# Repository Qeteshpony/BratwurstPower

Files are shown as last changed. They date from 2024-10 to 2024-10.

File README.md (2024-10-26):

# BratwurstPower



3D Render Top
3D Render Bottom

[Hardware Documentation](https://qeteshpony.github.io/BratwurstPower)

### What's this?

A power supply for a complete, Raspberry Pi based ADS-B Receiver Setup with independent power rails for the different components.

We sometimes face the problem that a normal Raspberry Pi power supply does not deliver enough power for the Raspi itself, the SDR Stick and possible other components like a display or even an SSD. 

This board can be mounted underneath a Raspberry Pi and deliver stable 5.x V with up to 3 A to it. 

In addition to that it can supply two USB devices and another external device with also 5.x V and 3 A each, provided the input has enough power and the maximum input current does not surpass 5A. 

Each outputs voltage can be calibrated from ~5.06 to ~5.6 V with a trimpot and the two USB outputs are passing USB2 signals from two USB-C connectors that can be hooked up to the Raspberry Pi. If you need USB3, you can use an external Y-cable. 

## What else is on the board?

The onboard circuitry is powered by its own 3.3V LDO regulator which is fed by the power rail for the Raspberry Pi since that one is always running. The LDO can provide a maximum of 200mA to also power small external loads on the GPIO connector. 

There is an INA219 power monitor connected to the main input and each output with a 10mΩ shunt resistor to measure current and voltage. 

The onboard I2C bus is connected to all of the INA219 and a PCA9557

| Device  | I2C-Address |
|:---|:---|
| INA219 Raspi | 0x40 |
| INA219 USB1  | 0x41 |
| INA219 USB2  | 0x42 |
| INA219 EXT | 0x43 |
| INA219 Main  | 0x44 |
| PCA9557 | 0x1F |

The PCA9557 I/O expander allows to switch off power to the USB-ports and the external power. It also has an LED connected that can be used for showing a warning state or similar. The other 4 pins are broken out on a header.

| PCA9557 Pin | Function |
|:---|:---|
| IO0 | LED  |
| IO1 | GPIO 1 (Opt: Raspi EN) |
| IO2 | GPIO 2 |
| IO3 | GPIO 3 |
| IO4 | GPIO 4 |
| IO5 | USB2 EN |
| IO6 | USB1 EN |
| IO7 | EXT EN |

Each voltage channel has a solder jumper to force-enable it. The USB power rails are also enabled as soon as their input usb port gets connected to the Raspberry Pi. In addition to that, all three external power connections can be controlled by the PCA9557 and there is an optional connection through a solder jumper to even give control over the Raspberry Pi power supply in case the I2C components on this board are controlled externally e.g. by an ESP. 

### External connections and jumpers
| Designator | Function |
|:---|:---|
| IN | Main Power supply - can be powered with 7 to 17V DC with a maximum of 5A. Nominal Power: 12V. |
| Raspi | Power supply for the Raspberry Pi. This is the only port that is by default always on. |
| USB1/2 in | USB input for external connections. Connect these to the Raspberry pi with normal USB cables. |
| USB1/2 out | Powered USB output for external components, each with its own power supply. |
| EXT | Power supply for other external components, also independently powered. Needs to be enabled through its solder jumper or by the PCA9557. |
| 2x I2C | I2C connection to either the Raspberry Pi or an external controller. The 3.3V connection is just a path-through between the connectors. |
| OTG | Optional connector to access the Raspberry Pis USB-OTG functionality. |
| GPIO | Optional header to use the free pins of the PCA9557. Keep in mind that the onboard 3.3V LDO can not provide more than 200mA. |
| USB1/2 EN | Solder jumper to force-enable the USB power supplies in case you want to use them without a connection to the Raspberry Pi. |
| EXT EN | Solder jumper to enable the EXT power supply. |
| Raspi EN | Solder jumper to connect the EN pin if the Raspi power supply with IO1 of the PCA9557. This can be used to externally hard-reset the Raspberry Pi and should only be used when the board is controlled by an external controller like an ESP. |
| TP1 | Test point to measure the voltage on the Raspberry Pi power supply. |
| TP2 | Test point to measure the voltage on the USB1 power supply. |
| TP3 | Test point to measure the voltage on the USB2 power supply. |
| TP4 | Test point to measure the voltage on the EXT power supply. |
| RV1 | Calibration Potentiometer for the Raspberry Pi power supply. |
| RV2 | Calibration Potentiometer for the USB1 power supply. |
| RV3 | Calibration Potentiometer for the USB2 power supply. |
| RV4 | Calibration Potentiometer for the EXT power supply. |

### Software

Example software to control and monitor this device with Home Assistant can be found [here](https://github.com/Qeteshpony/BratwurstPower.py).

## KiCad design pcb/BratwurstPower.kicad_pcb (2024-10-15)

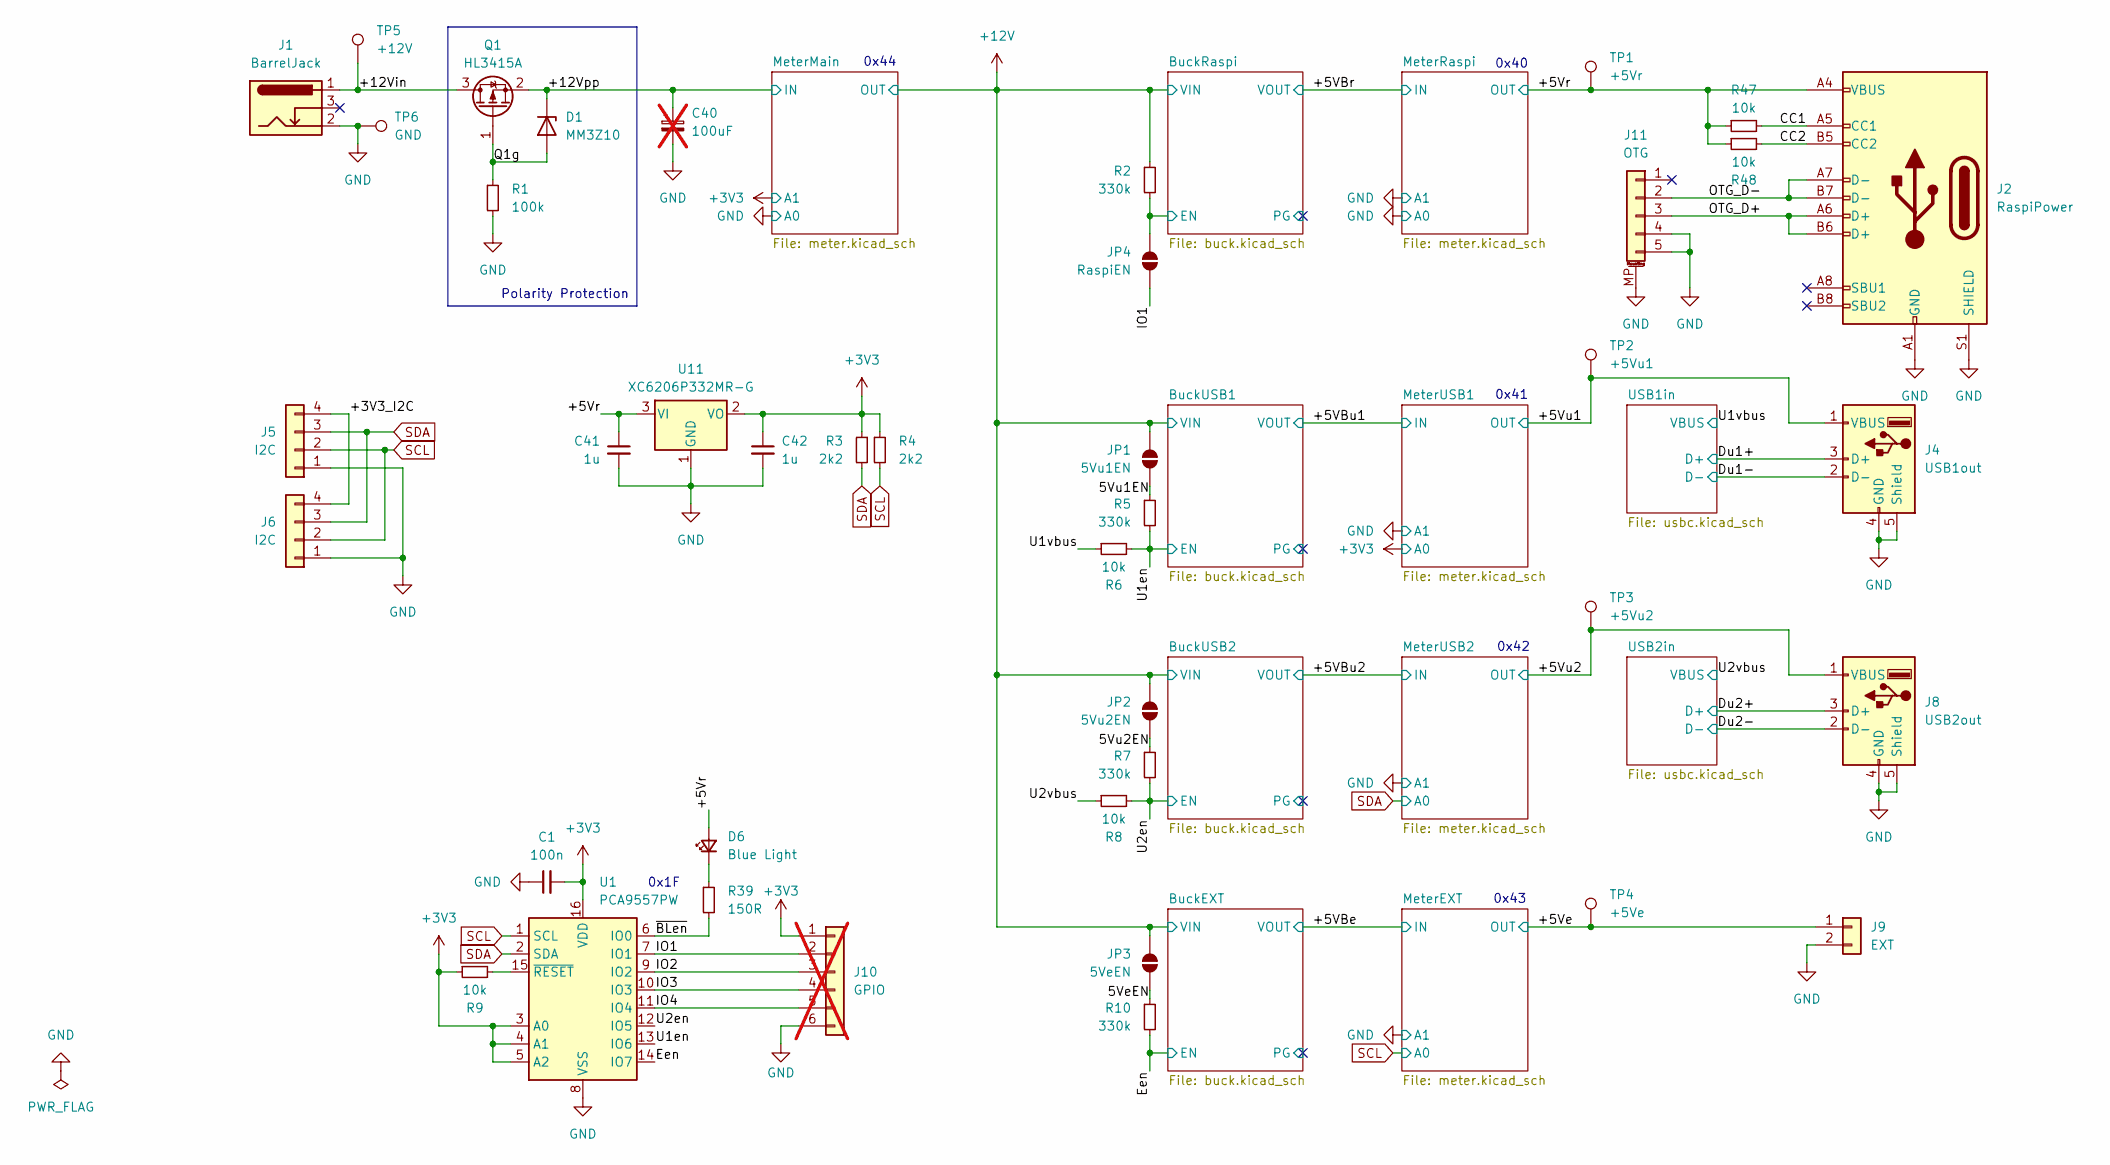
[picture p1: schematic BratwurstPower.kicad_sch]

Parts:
C1: 100n; C_0402_1005Metric; LCSC C307331
C40: 100uF; CP_Radial_D6.3mm_P2.50mm; not fitted
C41, C42: 1u; C_0402_1005Metric; LCSC C52923
D1: MM3Z10; D_SOD-323F; LCSC C19077459
D6: Blue Light; LED_0603_1608Metric_Pad1.05x0.95mm_HandSolder; LCSC C72041
J1: BarrelJack; BarrelJack_Combined
J2: RaspiPower; USB_C_Receptacle_GCT_USB4105-xx-A_16P_TopMnt_Horizontal; LCSC C2988369
J4: USB1out; USB_A_Molex_67643_Horizontal; LCSC C2798029
J5, J6: I2C; JST_PH_S4B-PH-K_1x04_P2.00mm_Horizontal; LCSC C265452
J8: USB2out; USB_A_Molex_67643_Horizontal; LCSC C2798029
J9: EXT; JST_XH_S2B-XH-A_1x02_P2.50mm_Horizontal; LCSC C157931
J10: GPIO; PinHeader_1x06_P2.54mm_Vertical; not fitted
J11: OTG; JST_SH_SM05B-SRSS-TB_1x05-1MP_P1.00mm_Horizontal; LCSC C160404
JP1: 5Vu1EN; SolderJumper-2_P1.3mm_Open_TrianglePad1.0x1.5mm
JP2: 5Vu2EN; SolderJumper-2_P1.3mm_Open_TrianglePad1.0x1.5mm
JP3: 5VeEN; SolderJumper-2_P1.3mm_Open_TrianglePad1.0x1.5mm
JP4: RaspiEN; SolderJumper-2_P1.3mm_Open_TrianglePad1.0x1.5mm
Q1: HL3415A; SOT-23; LCSC C28646270
R1: 100k; R_0402_1005Metric; LCSC C25741
R2, R5, R7, R10: 330k; R_0402_1005Metric; LCSC C25778
R3, R4: 2k2; R_0402_1005Metric; LCSC C25879
R6, R8, R9, R47, R48: 10k; R_0402_1005Metric; LCSC C25744
R39: 150R; R_0402_1005Metric; LCSC C25082
TP1: +5Vr; TestPoint_THTPad_D1.0mm_Drill0.5mm
TP2: +5Vu1; TestPoint_THTPad_D1.0mm_Drill0.5mm
TP3: +5Vu2; TestPoint_THTPad_D1.0mm_Drill0.5mm
TP4: +5Ve; TestPoint_THTPad_D1.0mm_Drill0.5mm
TP5: +12V; TestPoint_THTPad_D2.0mm_Drill1.0mm
TP6: GND; TestPoint_THTPad_D2.0mm_Drill1.0mm
U1: PCA9557PW; TSSOP-16_4.4x5mm_P0.65mm; LCSC C141380
U11: XC6206P332MR-G; SOT-23-3; LCSC C5446

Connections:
+3V3: C1.2, C42.1, J10.1, R3.1, R4.1, R9.1, U1.3 (A0), U1.4 (A1), U1.5 (A2), U1.16 (VDD), U11.2 (VO); also elsewhere on the board
+12V: JP1.2 (B), JP2.2 (B), JP3.2 (B), R2.1; also elsewhere on the board
/5VeEN: JP3.1 (A), R10.1
/5Vu1EN: JP1.1 (A), R5.1
/5Vu2EN: JP2.1 (A), R7.1
/+3V3_I2C: J5.4, J6.4
/+5Ve: J9.1, TP4.1; also elsewhere on the board
/+5Vr: C41.1, D6.2 (A), J2.A4 (VBUS), J2.A9 (VBUS), J2.B4 (VBUS), J2.B9 (VBUS), R47.1, R48.1, TP1.1, U11.3 (VI); also elsewhere on the board
/+5Vu1: J4.1 (VBUS), TP2.1; also elsewhere on the board
/+5Vu2: J8.1 (VBUS), TP3.1; also elsewhere on the board
/+12Vin: J1.1, Q1.3 (D), TP5.1
/+12Vpp: C40.1, D1.1 (K), Q1.2 (S); also elsewhere on the board
/BuckRaspi/EN: JP4.2 (B), R2.2; also elsewhere on the board
/CC1: J2.A5 (CC1), R47.2
/CC2: J2.B5 (CC2), R48.2
/Du1+: J4.3 (D+); also elsewhere on the board
/Du1-: J4.2 (D-); also elsewhere on the board
/Du2+: J8.3 (D+); also elsewhere on the board
/Du2-: J8.2 (D-); also elsewhere on the board
/Een: R10.2, U1.14 (IO7); also elsewhere on the board
/IO1: J10.2, JP4.1 (A), U1.7 (IO1)
/IO2: J10.3, U1.9 (IO2)
/IO3: J10.4, U1.10 (IO3)
/IO4: J10.5, U1.11 (IO4)
/OTG_D+: J2.A6 (D+), J2.B6 (D+), J11.3
/OTG_D-: J2.A7 (D-), J2.B7 (D-), J11.2
/Q1g: D1.2 (A), Q1.1 (G), R1.1
/U1en: R5.2, R6.2, U1.13 (IO6); also elsewhere on the board
/U1vbus: R6.1; also elsewhere on the board
/U2en: R7.2, R8.2, U1.12 (IO5); also elsewhere on the board
/U2vbus: R8.1; also elsewhere on the board
/~BLen: R39.2, U1.6 (IO0)
GND: C1.1, C40.2, C41.2, C42.2, J1.2, J2.A1 (GND), J2.A12 (GND), J2.B1 (GND), J2.B12 (GND), J2.S1 (SHIELD), J4.4 (GND), J4.5 (Shield), J5.1, J6.1, J8.4 (GND), J8.5 (Shield), J9.2, J10.6, J11.4, J11.5, J11.MP (MountPin), R1.2, TP6.1, U1.8 (VSS), U11.1 (GND); also elsewhere on the board
unnamed: D6.1 (K), R39.1
unnamed: R9.2, U1.15 (~RESET)
SCL: J5.2, J6.2, R4.2, U1.1 (SCL); also elsewhere on the board
SDA: J5.3, J6.3, R3.2, U1.2 (SDA); also elsewhere on the board

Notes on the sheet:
Polarity Protection
0x41
0x1F
0x44
0x40
0x43
0x42

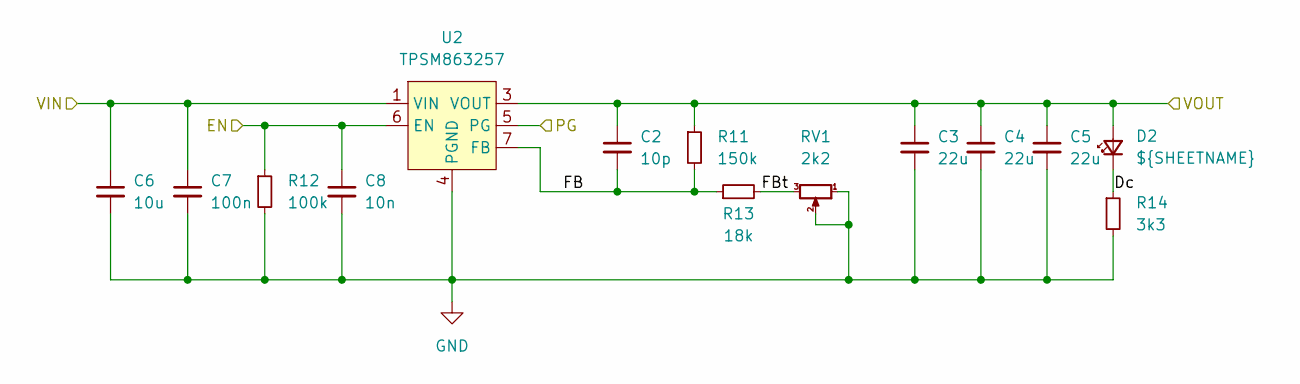
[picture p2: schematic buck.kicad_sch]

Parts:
C2: 10p; C_0402_1005Metric; LCSC C32949
C3, C4, C5: 22u; C_0805_2012Metric; LCSC C45783
C6: 10u; C_0805_2012Metric; LCSC C15850
C7: 100n; C_0402_1005Metric; LCSC C307331
C8: 10n; C_0402_1005Metric; LCSC C15195
D2: ${SHEETNAME}; LED_0603_1608Metric; LCSC C72038
R11: 150k; R_0402_1005Metric; LCSC C25755
R12: 100k; R_0402_1005Metric; LCSC C25741
R13: 18k; R_0402_1005Metric; LCSC C25762
R14: 3k3; R_0402_1005Metric; LCSC C25890
RV1: 2k2; Potentiometer_hdk_VG039NCHXT; LCSC C145162
U2: TPSM863257; QFN-FCMOD; LCSC C19190416

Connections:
+12V: C6.1, C7.1, U2.1 (VIN); also elsewhere on the board
/+5VBr: C2.1, C3.1, C4.1, C5.1, D2.2 (A), R11.1, U2.3 (VOUT); also elsewhere on the board
/BuckRaspi/Dc: D2.1 (K), R14.1
/BuckRaspi/EN: C8.1, R12.1, U2.6 (EN); also elsewhere on the board
/BuckRaspi/FB: C2.2, R11.2, R13.1, U2.7 (FB)
/BuckRaspi/FBt: R13.2, RV1.3
/BuckRaspi/PG: U2.5 (PG)
GND: C3.2, C4.2, C5.2, C6.2, C7.2, C8.2, R12.2, R14.2, RV1.1, RV1.2, U2.4 (PGND); also elsewhere on the board

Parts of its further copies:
C9, C16, C23: 10p; C_0402_1005Metric; LCSC C32949
C10, C11, C12, C17, C18, C19, C24, C25, C26: 22u; C_0805_2012Metric; LCSC C45783
C13, C20, C27: 10u; C_0805_2012Metric; LCSC C15850
C14, C21, C28: 100n; C_0402_1005Metric; LCSC C307331
C15, C22, C29: 10n; C_0402_1005Metric; LCSC C15195
R15, R19, R23: 150k; R_0402_1005Metric; LCSC C25755
R16, R20, R24: 100k; R_0402_1005Metric; LCSC C25741
R17, R21, R25: 18k; R_0402_1005Metric; LCSC C25762
R18, R22, R26: 3k3; R_0402_1005Metric; LCSC C25890
RV2, RV3, RV4: 2k2; Potentiometer_hdk_VG039NCHXT; LCSC C145162
U3, U4, U5: TPSM863257; QFN-FCMOD; LCSC C19190416

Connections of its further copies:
+12V: C13.1, C14.1, C20.1, C21.1, C27.1, C28.1, U3.1 (VIN), U4.1 (VIN), U5.1 (VIN); also elsewhere on the board
/+5VBe: C23.1, C24.1, C25.1, C26.1, R23.1, U5.3 (VOUT); also elsewhere on the board
/+5VBu1: C9.1, C10.1, C11.1, C12.1, R15.1, U3.3 (VOUT); also elsewhere on the board
/+5VBu2: C16.1, C17.1, C18.1, C19.1, R19.1, U4.3 (VOUT); also elsewhere on the board
/BuckEXT/Dc: R26.1; also elsewhere on the board
/BuckEXT/FB: C23.2, R23.2, R25.1, U5.7 (FB)
/BuckEXT/FBt: R25.2, RV4.3
/BuckEXT/PG: U5.5 (PG)
/BuckUSB1/Dc: R18.1; also elsewhere on the board
/BuckUSB1/FB: C9.2, R15.2, R17.1, U3.7 (FB)
/BuckUSB1/FBt: R17.2, RV2.3
/BuckUSB1/PG: U3.5 (PG)
/BuckUSB2/Dc: R22.1; also elsewhere on the board
/BuckUSB2/FB: C16.2, R19.2, R21.1, U4.7 (FB)
/BuckUSB2/FBt: R21.2, RV3.3
/BuckUSB2/PG: U4.5 (PG)
/Een: C29.1, R24.1, U5.6 (EN); also elsewhere on the board
/U1en: C15.1, R16.1, U3.6 (EN); also elsewhere on the board
/U2en: C22.1, R20.1, U4.6 (EN); also elsewhere on the board
GND: C10.2, C11.2, C12.2, C13.2, C14.2, C15.2, C17.2, C18.2, C19.2, C20.2, C21.2, C22.2, C24.2, C25.2, C26.2, C27.2, C28.2, C29.2, R16.2, R18.2, R20.2, R22.2, R24.2, R26.2, RV2.1, RV2.2, RV3.1, RV3.2, RV4.1, RV4.2, U3.4 (PGND), U4.4 (PGND), U5.4 (PGND); also elsewhere on the board

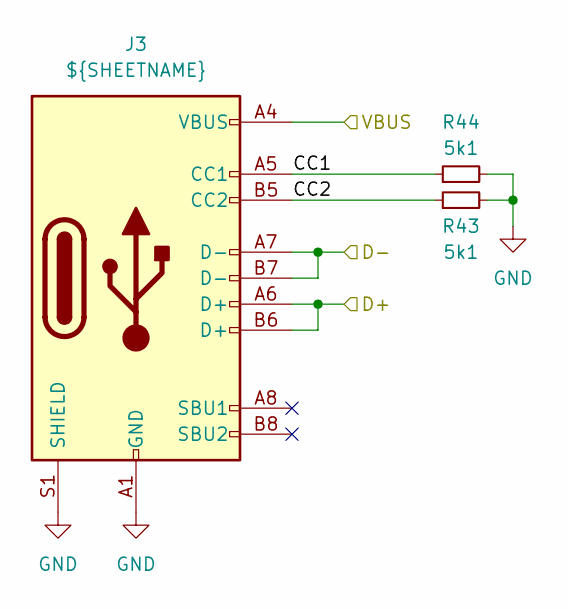
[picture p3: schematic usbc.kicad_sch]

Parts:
J3: ${SHEETNAME}; USB_C_Receptacle_GCT_USB4105-xx-A_16P_TopMnt_Horizontal; LCSC C2988369
R43, R44: 5k1; R_0402_1005Metric; LCSC C25905

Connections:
/Du1+: J3.A6 (D+), J3.B6 (D+); also elsewhere on the board
/Du1-: J3.A7 (D-), J3.B7 (D-); also elsewhere on the board
/U1vbus: J3.A4 (VBUS), J3.A9 (VBUS), J3.B4 (VBUS), J3.B9 (VBUS); also elsewhere on the board
/USB1in/CC1: J3.A5 (CC1), R44.1
/USB1in/CC2: J3.B5 (CC2), R43.1
GND: J3.A1 (GND), J3.A12 (GND), J3.B1 (GND), J3.B12 (GND), J3.S1 (SHIELD), R43.2, R44.2; also elsewhere on the board

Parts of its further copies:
R45, R46: 5k1; R_0402_1005Metric; LCSC C25905

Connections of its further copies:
/USB2in/CC1: R45.1; also elsewhere on the board
/USB2in/CC2: R46.1; also elsewhere on the board
GND: R45.2, R46.2; also elsewhere on the board

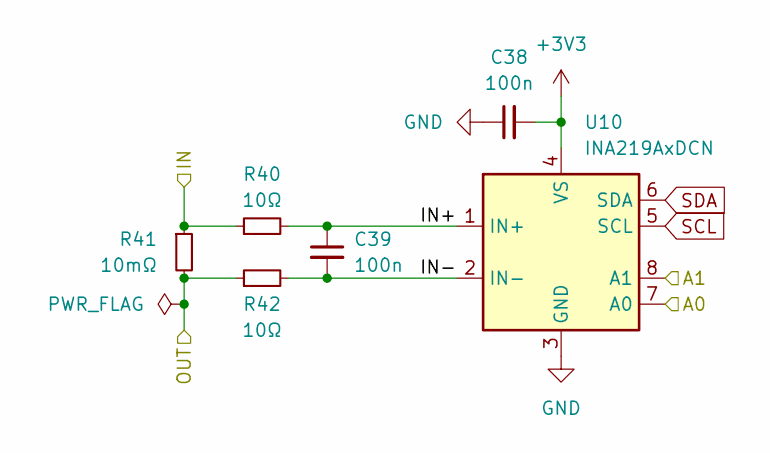
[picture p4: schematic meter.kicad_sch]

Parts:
C38, C39: 100n; C_0402_1005Metric; LCSC C307331
R40, R42: 10Ω; R_0402_1005Metric; LCSC C25077
R41: 10mΩ; R_1206_3216Metric; LCSC C2961483
U10: INA219AxDCN; SOT-23-8; LCSC C87469

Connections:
+3V3: C38.2, U10.4 (VS), U10.8 (A1); also elsewhere on the board
+12V: R41.2, R42.1; also elsewhere on the board
/+12Vpp: R40.1, R41.1; also elsewhere on the board
/MeterMain/IN+: C39.1, R40.2, U10.1 (IN+)
/MeterMain/IN-: C39.2, R42.2, U10.2 (IN-)
GND: C38.1, U10.3 (GND), U10.7 (A0); also elsewhere on the board
SCL: U10.5 (SCL); also elsewhere on the board
SDA: U10.6 (SDA); also elsewhere on the board

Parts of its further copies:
C30, C31, C32, C33, C34, C35, C36, C37: 100n; C_0402_1005Metric; LCSC C307331
R27, R29, R30, R32, R33, R35, R36, R38: 10Ω; R_0402_1005Metric; LCSC C25077
R28, R31, R34, R37: 10mΩ; R_1206_3216Metric; LCSC C2961483
U6, U7, U8, U9: INA219AxDCN; SOT-23-8; LCSC C87469

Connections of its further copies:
+3V3: C30.2, C32.2, C34.2, C36.2, U6.4 (VS), U7.4 (VS), U7.7 (A0), U8.4 (VS), U9.4 (VS); also elsewhere on the board
/+5VBe: R36.1, R37.1; also elsewhere on the board
/+5VBr: R27.1, R28.1; also elsewhere on the board
/+5VBu1: R30.1, R31.1; also elsewhere on the board
/+5VBu2: R33.1, R34.1; also elsewhere on the board
/+5Ve: R37.2, R38.1; also elsewhere on the board
/+5Vr: R28.2, R29.1; also elsewhere on the board
/+5Vu1: R31.2, R32.1; also elsewhere on the board
/+5Vu2: R34.2, R35.1; also elsewhere on the board
/MeterEXT/IN+: C37.1, R36.2, U9.1 (IN+)
/MeterEXT/IN-: C37.2, R38.2, U9.2 (IN-)
/MeterRaspi/IN+: C31.1, R27.2, U6.1 (IN+)
/MeterRaspi/IN-: C31.2, R29.2, U6.2 (IN-)
/MeterUSB1/IN+: C33.1, R30.2, U7.1 (IN+)
/MeterUSB1/IN-: C33.2, R32.2, U7.2 (IN-)
/MeterUSB2/IN+: C35.1, R33.2, U8.1 (IN+)
/MeterUSB2/IN-: C35.2, R35.2, U8.2 (IN-)
GND: C30.1, C32.1, C34.1, C36.1, U6.3 (GND), U6.7 (A0), U6.8 (A1), U7.3 (GND), U7.8 (A1), U8.3 (GND), U8.8 (A1), U9.3 (GND), U9.8 (A1); also elsewhere on the board
SCL: U6.5 (SCL), U7.5 (SCL), U8.5 (SCL), U9.5 (SCL), U9.7 (A0); also elsewhere on the board
SDA: U6.6 (SDA), U7.6 (SDA), U8.6 (SDA), U8.7 (A0), U9.6 (SDA); also elsewhere on the board

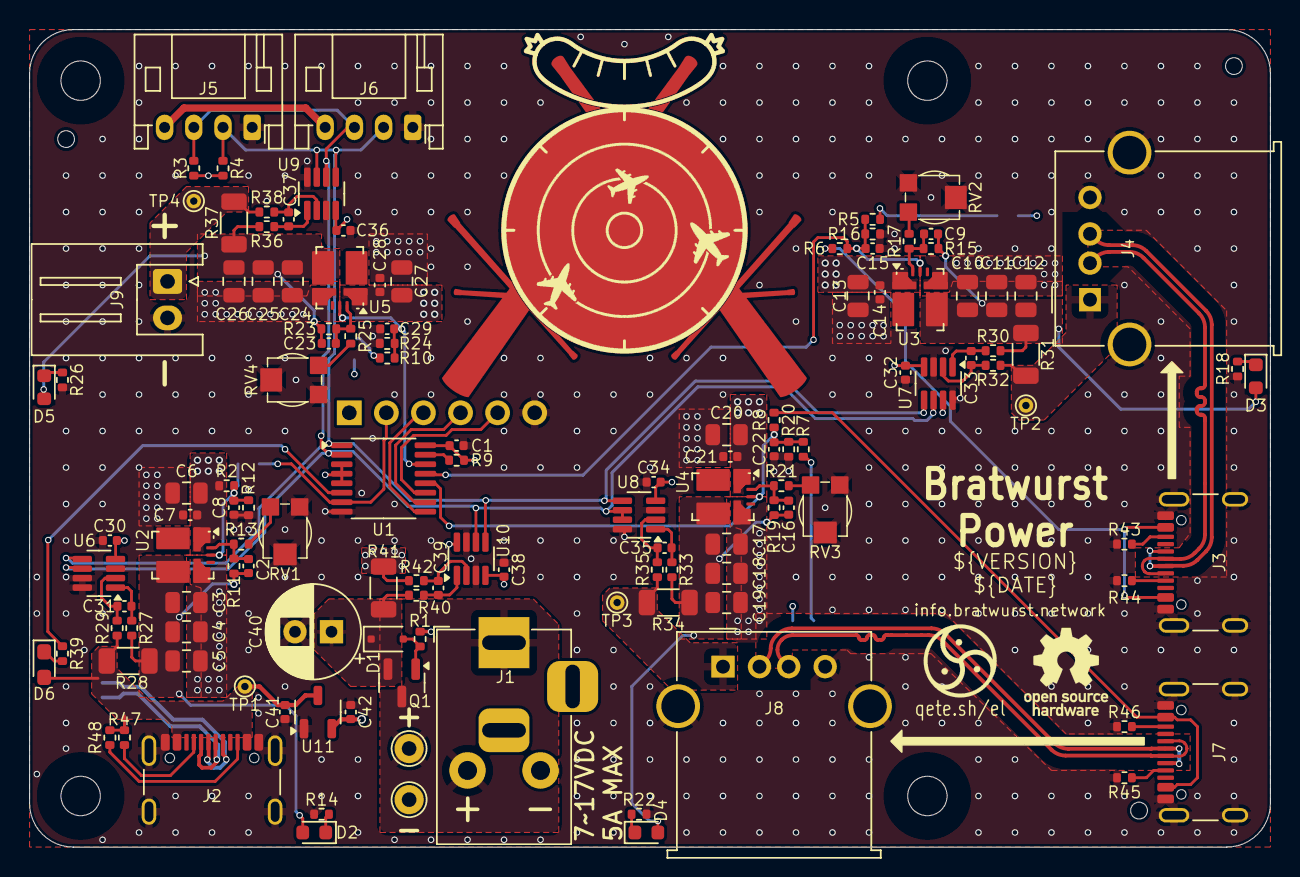
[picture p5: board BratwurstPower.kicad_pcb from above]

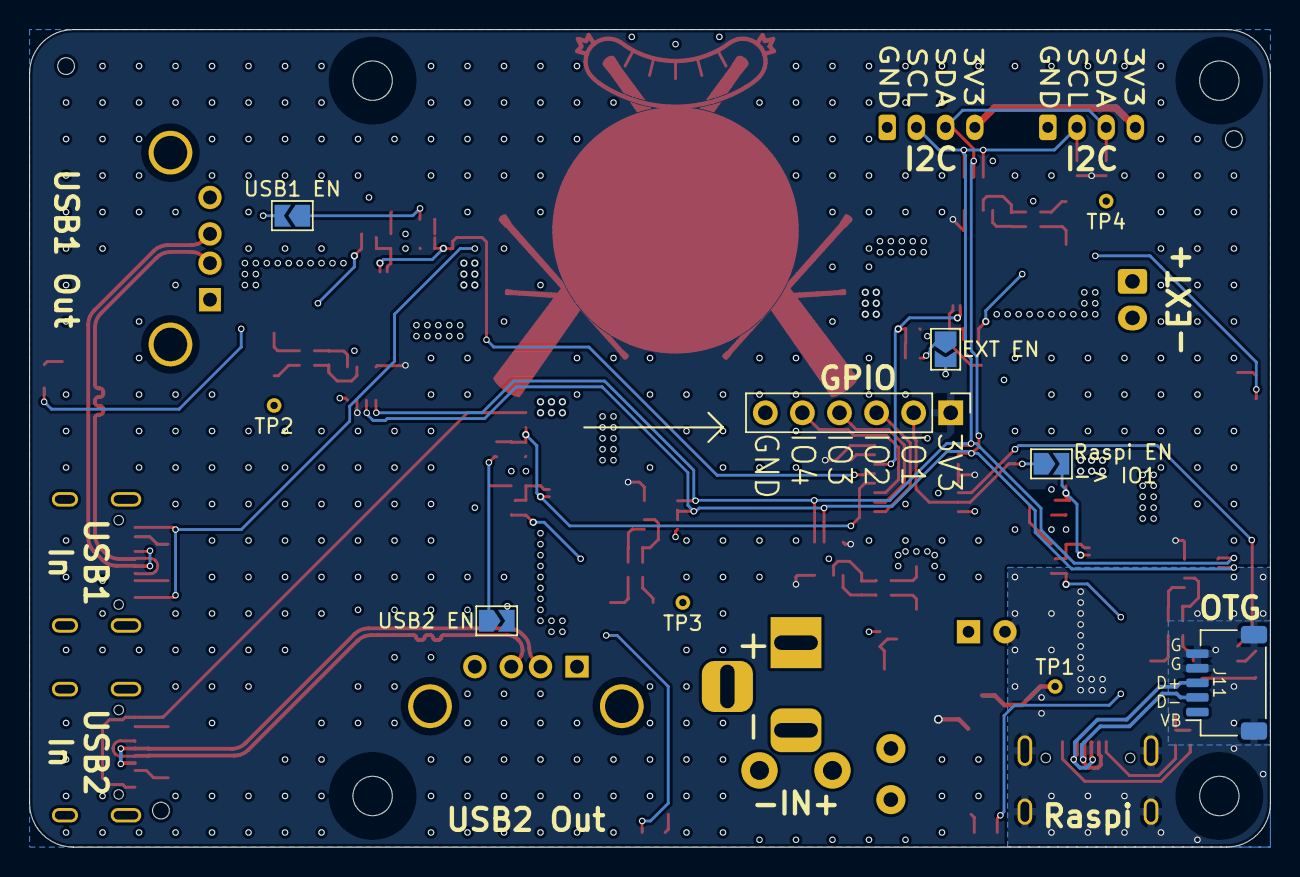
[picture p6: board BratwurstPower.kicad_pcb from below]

Board: 4 copper layers, 85.0 x 56.0 mm, 133 parts (6 on the bottom side), 67 nets.

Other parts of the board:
D3: BuckUSB1; LED_0603_1608Metric
D4: BuckUSB2; LED_0603_1608Metric
D5: BuckEXT; LED_0603_1608Metric
J7: USB2in; USB_C_Receptacle_GCT_USB4105-xx-A_16P_TopMnt_Horizontal

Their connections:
/+5VBe: D5.2 (A); also elsewhere on the board
/+5VBu1: D3.2 (A); also elsewhere on the board
/+5VBu2: D4.2 (A); also elsewhere on the board
/BuckEXT/Dc: D5.1 (K); also elsewhere on the board
/BuckUSB1/Dc: D3.1 (K); also elsewhere on the board
/BuckUSB2/Dc: D4.1 (K); also elsewhere on the board
/Du2+: J7.A6 (D+), J7.B6 (D+); also elsewhere on the board
/Du2-: J7.A7 (D-), J7.B7 (D-); also elsewhere on the board
/U2vbus: J7.A4 (VBUS), J7.A9 (VBUS), J7.B4 (VBUS), J7.B9 (VBUS); also elsewhere on the board
/USB2in/CC1: J7.A5 (CC1); also elsewhere on the board
/USB2in/CC2: J7.B5 (CC2); also elsewhere on the board
GND: J7.A1 (GND), J7.A12 (GND), J7.B1 (GND), J7.B12 (GND), J7.S1 (SHIELD); also elsewhere on the board

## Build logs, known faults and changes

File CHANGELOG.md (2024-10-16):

# Changelog

## [2.1.0](https://github.com/Qeteshpony/BratwurstPower/compare/v2.0.0...v2.1.0) (2024-10-15)

### Features

* add 3.3V LDO for I2C circuitry ([2b5c3bb](https://github.com/Qeteshpony/BratwurstPower/commit/2b5c3bbb7843f55926b5f1e81e538d522e31e35b))
* optional connection RaspiEN to IO1 ([70316f4](https://github.com/Qeteshpony/BratwurstPower/commit/70316f4371bf1865683d0fed5eac409bfbf7f759))

### Bug Fixes

* add thermal relief to USB ports ([c1cdf07](https://github.com/Qeteshpony/BratwurstPower/commit/c1cdf074c5c48fcf30c5e46d3135f11b78604dbd))
* change pots to 2.2kΩ ([30dea97](https://github.com/Qeteshpony/BratwurstPower/commit/30dea97b3c8bd866a6abc039f84854dd3e50c406))
* few missing gnd vias ([faeb505](https://github.com/Qeteshpony/BratwurstPower/commit/faeb505406acb9fb4c7d40617cce8159f10d0e6d))
* part numbers ([30dea97](https://github.com/Qeteshpony/BratwurstPower/commit/30dea97b3c8bd866a6abc039f84854dd3e50c406))

## [2.0.0](https://github.com/Qeteshpony/BratwurstPower/compare/v1.0.0...v2.0.0) (2024-10-13)

### ⚠ BREAKING CHANGES

* Replace USB mini and Raspi port with USB-C

### Features

* add connector for USB OTG connection ([87fe823](https://github.com/Qeteshpony/BratwurstPower/commit/87fe823e94b833d1a0f5c317ec925b5917b6bf1c))
* Replace USB mini and Raspi port with USB-C ([87fe823](https://github.com/Qeteshpony/BratwurstPower/commit/87fe823e94b833d1a0f5c317ec925b5917b6bf1c))

### Bug Fixes

* add capacitor to 3V3 rail ([2a91989](https://github.com/Qeteshpony/BratwurstPower/commit/2a91989fa952c24f299fbd1cccfdc1305d00f5c8))
* add clearance around USB traces ([64b67dd](https://github.com/Qeteshpony/BratwurstPower/commit/64b67ddab612e38d8eadc1a45ddca2e44e5cca85))
* add copper under silkscreen ([0eb251c](https://github.com/Qeteshpony/BratwurstPower/commit/0eb251c24585daa32aa4f257d0572fac3db576bc))
* add GND plane on top layer ([5fe6761](https://github.com/Qeteshpony/BratwurstPower/commit/5fe676162f0ecc641008cbd7f207ba13c2c5c243))
* part numbers ([1900d4c](https://github.com/Qeteshpony/BratwurstPower/commit/1900d4c72c88179a9a271730e865d1acf6648d65))
* remove accidental antennas ([9da1ef0](https://github.com/Qeteshpony/BratwurstPower/commit/9da1ef002d8e76d86329d41a801374e329e6e917))
* via stitching between GND layers ([d20805e](https://github.com/Qeteshpony/BratwurstPower/commit/d20805ef16ecb8689d480c174ccf6b0245784b35))

## 1.0.0 (2024-09-28)

### Features

* add more functionality ([42bf073](https://github.com/Qeteshpony/BratwurstPower/commit/42bf073b20a51192894266ed7dfc9010e4ff245c))
* add optional input cap ([f9ad5c0](https://github.com/Qeteshpony/BratwurstPower/commit/f9ad5c03f8debc085c511e0277daebb1d7ae47f8))
* featuritis ([288534c](https://github.com/Qeteshpony/BratwurstPower/commit/288534c0020067c35910bc5ae02d2f1ec86f82bd))
* initial release ([3299ec0](https://github.com/Qeteshpony/BratwurstPower/commit/3299ec04ed7b1eef2d23c607cb947eac6ff95e5c))
* polarity protection for I2C bus ([885937a](https://github.com/Qeteshpony/BratwurstPower/commit/885937a8c72dc8286b168822046114b54a5149ed))

### Bug Fixes

* I2C pull-up strength ([c746266](https://github.com/Qeteshpony/BratwurstPower/commit/c746266ec7d45d97dd51fba9e075a3c7b3abfd47))
* replace overlapping footprints with custom one ([f81d497](https://github.com/Qeteshpony/BratwurstPower/commit/f81d49716fe83ee318ac00b530015c5b3a7d0b12))
* update Bratwurst Logo ([0804f48](https://github.com/Qeteshpony/BratwurstPower/commit/0804f482d519870464805ea4f0b06169f02ff373))

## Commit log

2024-09-08 feat: initial release
    [BratwurstPower.kicad_pcb, BratwurstPower.kicad_sch, buck.kicad_sch]
2024-09-08 fix: replace overlapping footprints with custom one
    [BratwurstPower.kicad_pcb, BratwurstPower.kicad_sch, buck.kicad_sch]
2024-09-10 feat: add more functionality
    - INA power monitor on each output
    - I/O expander to reset usb ports if needed
    - Bratwurst Logo
    [BratwurstPower.kicad_pcb, BratwurstPower.kicad_sch, buck.kicad_sch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]
2024-09-10 feat: featuritis
    added too much stuff...
    [BratwurstPower.kicad_pcb, BratwurstPower.kicad_sch, meter.kicad_sch]
2024-09-10 chore: cleanup
    [BratwurstPower.kicad_sch, meter.kicad_sch]
2024-09-10 style: add fillets to copper zones
    [BratwurstPower.kicad_pcb]
2024-09-10 style: add info tables on bottom silkscreen
    [BratwurstPower.kicad_pcb]
2024-09-10 docs: update board properties
    [BratwurstPower.kicad_pcb]
2024-09-11 fix: update Bratwurst Logo
    [BratwurstPower.kicad_pcb]
2024-09-12 feat: add optional input cap
    [BratwurstPower.kicad_pcb, BratwurstPower.kicad_sch]
2024-09-12 chore: one shall save before committing
    [BratwurstPower.kicad_pcb]
2024-09-12 fix: I2C pull-up strength
    [BratwurstPower.kicad_pcb, BratwurstPower.kicad_sch]
2024-09-28 feat: polarity protection for I2C bus
    [BratwurstPower.kicad_pcb, BratwurstPower.kicad_sch]
2024-09-28 fix: add capacitor to 3V3 rail
    [BratwurstPower.kicad_pcb, BratwurstPower.kicad_sch]
2024-09-28 fix: add copper under silkscreen
    to avoid copper planes flooding the bratwurst
2024-09-28 fix: add GND plane on top layer
    [BratwurstPower.kicad_pcb]
2024-09-28 fix: via stitching between GND layers
    [BratwurstPower.kicad_pcb]
2024-09-28 fix: add clearance around USB traces
    [BratwurstPower.kicad_pcb]
2024-09-29 feat!: Replace USB mini and Raspi port with USB-C
    feat: add connector for USB OTG connection
    [BratwurstPower.kicad_pcb, BratwurstPower.kicad_sch, usbc.kicad_sch]
2024-09-29 style: replace OTG connector
    [BratwurstPower.kicad_pcb, BratwurstPower.kicad_sch, usbc.kicad_sch]
2024-09-29 docs: add measurements to board
    [BratwurstPower.kicad_pcb]
2024-09-30 fix: remove accidental antennas
    [BratwurstPower.kicad_pcb]
2024-10-13 style: silkscreen cleanup
    [BratwurstPower.kicad_pcb]
2024-10-13 fix: part numbers
    [BratwurstPower.kicad_pcb, BratwurstPower.kicad_sch]
2024-10-14 feat: add 3.3V LDO for I2C circuitry
    [BratwurstPower.kicad_pcb, BratwurstPower.kicad_sch]
2024-10-14 fix: change pots to 2.2kΩ
    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
    [BratwurstPower.kicad_pcb, BratwurstPower.kicad_sch, buck.kicad_sch]
2024-10-14 fix: add thermal relief to USB ports
    [BratwurstPower.kicad_pcb]
2024-10-14 fix: few missing gnd vias
    [BratwurstPower.kicad_pcb]
2024-10-14 style: silkscreen typo
    [BratwurstPower.kicad_pcb]
2024-10-14 style: silkscreen text
    [BratwurstPower.kicad_pcb]
2024-10-15 feat: optional connection RaspiEN to IO1
    In case external control of the I2C bus is taken, this can be used to hard-reset the Raspberry Pi
    [BratwurstPower.kicad_pcb, BratwurstPower.kicad_sch]
2024-10-15 style: update silkscreen
    Add some more silkscreen information to make identification of components easier
    [BratwurstPower.kicad_pcb]
